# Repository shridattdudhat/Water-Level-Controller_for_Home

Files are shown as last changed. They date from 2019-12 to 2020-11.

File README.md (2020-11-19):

# DIY_WaterLevel_For_Home
Simple Water Level Controller Using Arduino
Water Level
Automatic detects Water level of Tank and turn on and off motor according to it
https://shridatt.github.io
modified 27 Oct 2019 Diwali
by Shridatt Dudhat
           _            _
           |         G  |  => H
           |            |
           |            |
           |         R  |  => L
           |            |
           |            |
           \_________B__/  => GND
This code is in the public domain.
http://shridattdudhat.github.io









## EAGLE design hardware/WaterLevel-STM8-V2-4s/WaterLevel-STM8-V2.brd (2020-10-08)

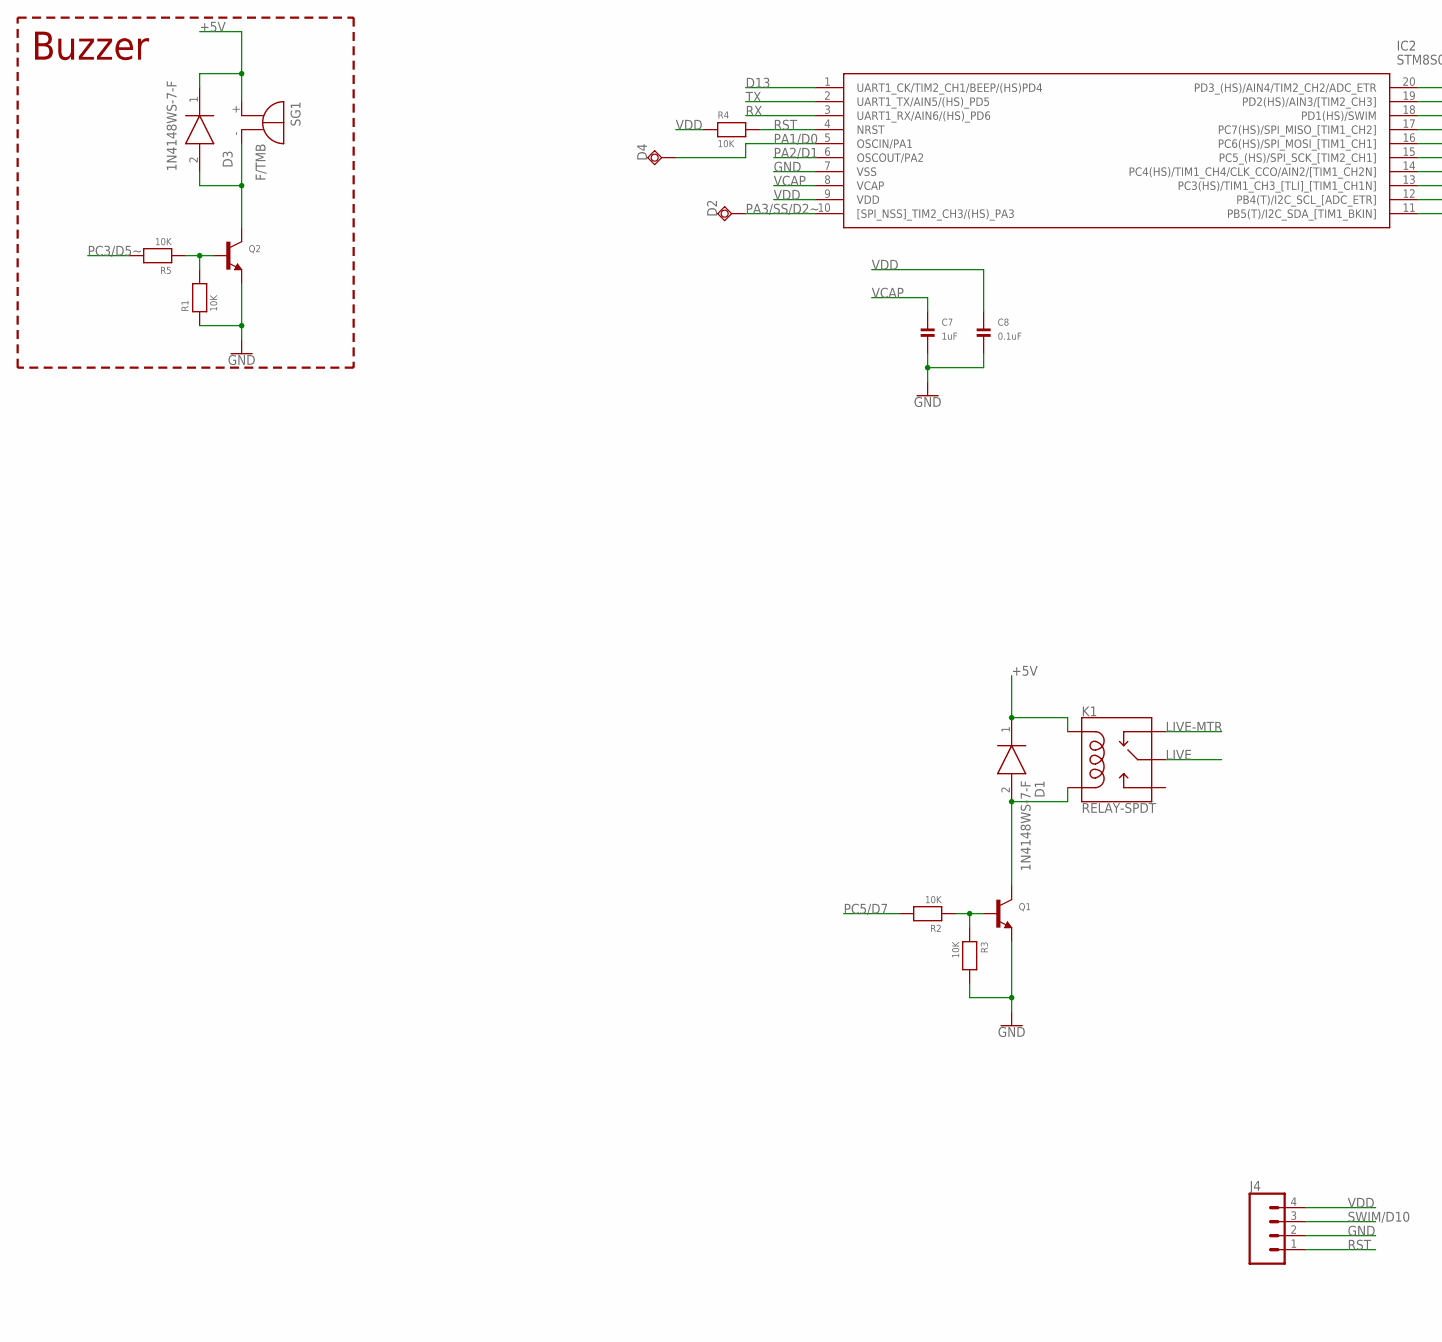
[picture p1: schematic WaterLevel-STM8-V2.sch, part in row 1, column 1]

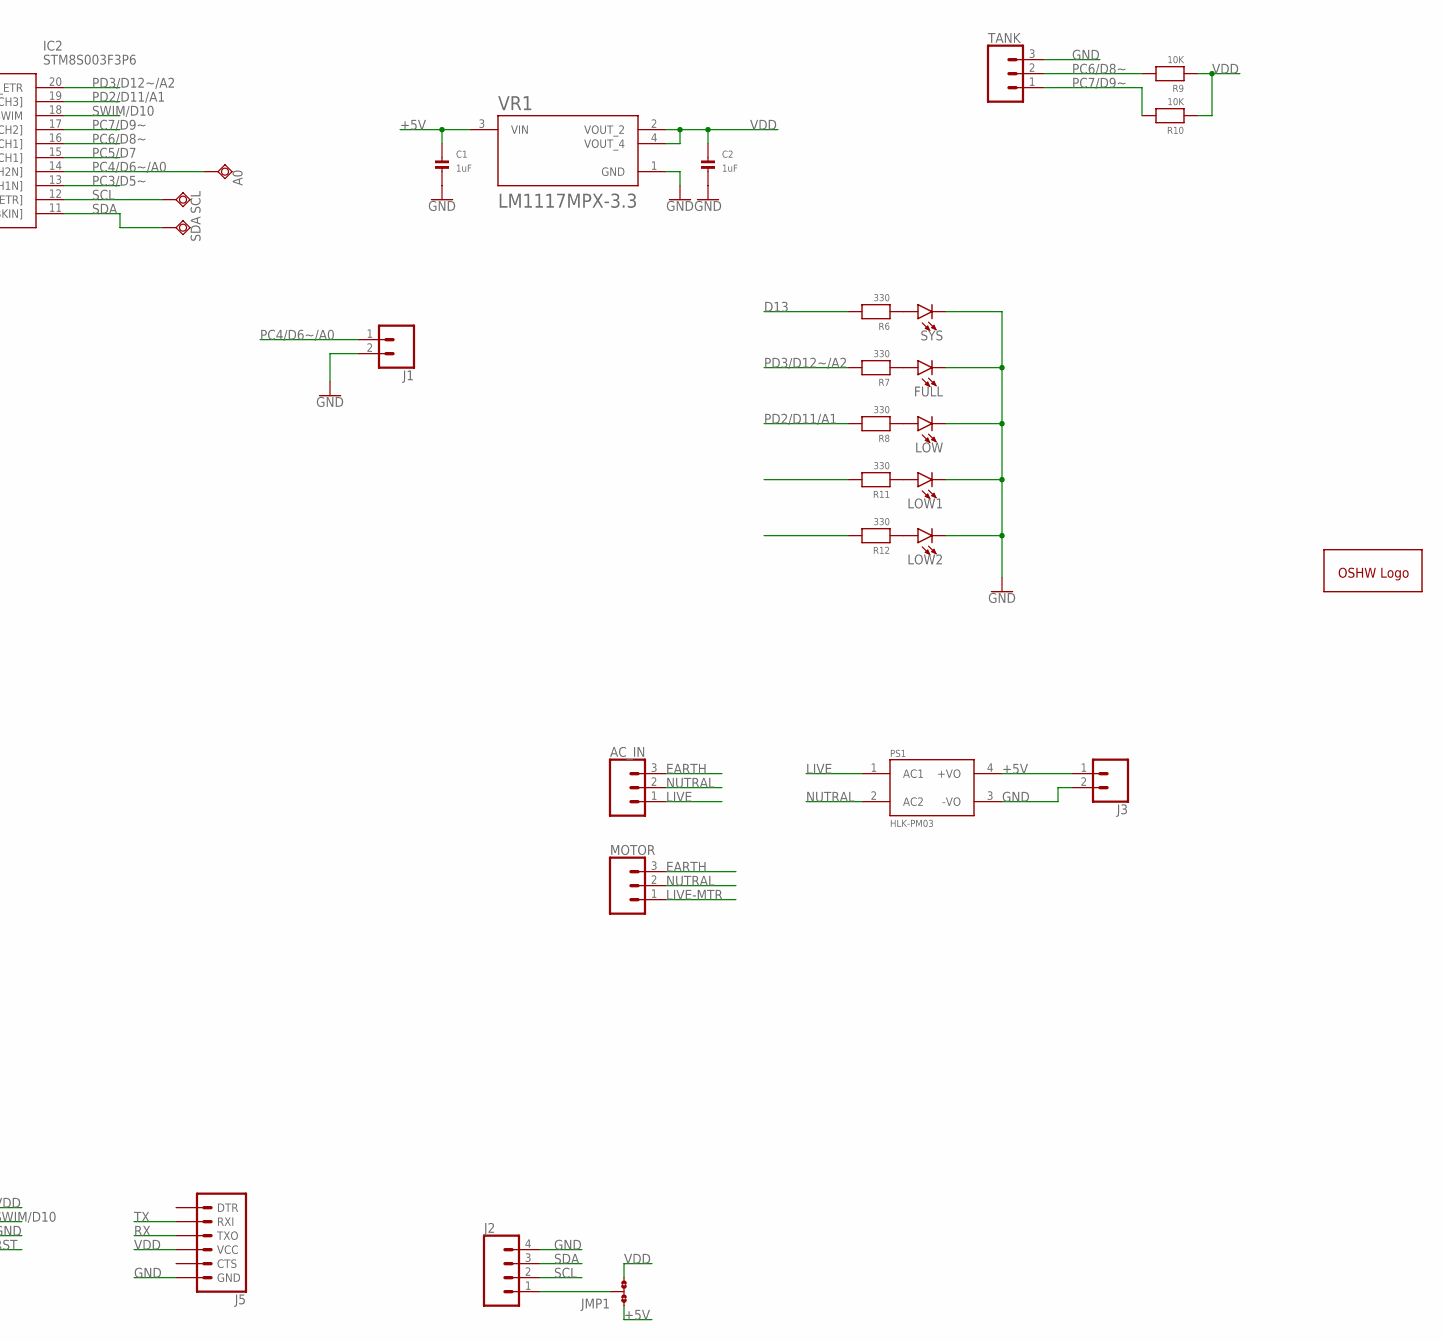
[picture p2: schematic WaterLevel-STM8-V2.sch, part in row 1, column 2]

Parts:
A0: TPSQTP20R; TP20R
AC_IN: SCREW-CONN_03-SCREW-5MM; SCREWTERMINAL-5MM-3
C1, C2, C7: 1uF; C0805
C8: 0.1uF; C0805
D1, D3: 1N4148WS-7-F; SOD2513X120N
D2, D4: TPSQTP20R; TP20R
FULL: LED-5MM-REC5MM; LED_5MM
GOLD_ORB_SM1: OSHWLOGOLOGO16MM; OSHW_16MM
IC2: STM8S003F3P6; SOP65P640X120-20N
J1, J3: 2PIN-2.54MM-POLARPOLAR; MOLEX-1X2
J2, J4: CONN_04PTH; 1X04
J5: 6_PIN_SERIAL_TARGETSILK; 6_PIN_SERIAL_TARGET_SIDE_W_SILK
JMP1: JMP-3-NO
K1: RELAY-SPDT; RELAY_G5LE
LOW, LOW1, LOW2: LED-5MM-REC5MM; LED_5MM
MOTOR: SCREW-CONN_03-SCREW-5MM; SCREWTERMINAL-5MM-3
PS1: HLK-PM03; CONV_HLK-PM03
Q1, Q2: TRANSISTOR_NPNWIDE; SOT23-WIDE
R1, R2, R3, R4, R5, R9, R10: 10K; R0805
R6, R7, R8, R11, R12: 330; R0805
SCL: TPSQTP20R; TP20R
SDA: TPSQTP20R; TP20R
SG1: F/TMB
SYS: LED-5MM-REC5MM; LED_5MM
TANK: SCREW-CONN_03-SCREW-5MM; SCREWTERMINAL-5MM-3
VR1: LM1117MPX-3.3; VREG_LM1117MPX-3.3

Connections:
+5V: C1.1, D1.1 (K), D3.1 (K), J3.1, JMP1.1, K1.2 (COIL1), PS1.4 (+VO), SG1.+, VR1.3 (VIN)
D13: IC2.1 (UART1_CK/TIM2_CH1/BEEP/(HS)PD4), R6.2
EARTH: AC_IN.3, MOTOR.3
GND: C1.2, C2.2, C7.2, C8.2, FULL.K (C), IC2.7 (VSS), J1.2, J2.4, J3.2, J4.2, J5.P$6 (GND), LOW.K (C), LOW1.K (C), LOW2.K (C), PS1.3 (-VO), Q1.2 (E), Q2.2 (E), R1.1, R3.2, SYS.K (C), TANK.3, VR1.1 (GND)
LIVE: AC_IN.1, K1.1 (MAIN), PS1.1 (AC1)
LIVE-MTR: K1.4 (NC), MOTOR.1
unnamed: R6.1, SYS.A
unnamed: D1.2 (A), K1.5 (COIL2), Q1.3 (C)
unnamed: Q1.1 (B), R2.1, R3.1
unnamed: D3.2 (A), Q2.3 (C), SG1.-
unnamed: Q2.1 (B), R1.2, R5.1
unnamed: FULL.A, R7.1
unnamed: LOW.A, R8.1
unnamed: J2.1, JMP1.2
unnamed: LOW1.A, R11.1
unnamed: LOW2.A, R12.1
NUTRAL: AC_IN.2, MOTOR.2, PS1.2 (AC2)
PA1/D0: D4.TP, IC2.5 (OSCIN/PA1)
PA2/D1: IC2.6 (OSCOUT/PA2)
PA3/SS/D2~: D2.TP, IC2.10 ([SPI_NSS]_TIM2_CH3/(HS)_PA3)
PC3/D5~: IC2.13 (PC3(HS)/TIM1_CH3_[TLI]_[TIM1_CH1N]), R5.2
PC4/D6~/A0: A0.TP, IC2.14 (PC4(HS)/TIM1_CH4/CLK_CCO/AIN2/[TIM1_CH2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), J1.1
PC5/D7: IC2.15 (PC5_(HS)/SPI_SCK_[TIM2_CH1]), R2.2
PC6/D8~: IC2.16 (PC6(HS)/SPI_MOSI_[TIM1_CH1]), R9.2, TANK.2
PC7/D9~: IC2.17 (PC7(HS)/SPI_MISO_[TIM1_CH2]), R10.2, TANK.1
PD2/D11/A1: IC2.19 (PD2(HS)/AIN3/[TIM2_CH3]), R8.2
PD3/D12~/A2: IC2.20 (PD3_(HS)/AIN4/TIM2_CH2/ADC_ETR), R7.2
RST: IC2.4 (NRST), J4.1, R4.2
RX: IC2.3 (UART1_RX/AIN6/(HS)_PD6), J5.P$2 (TXO)
SCL: IC2.12 (PB4(T)/I2C_SCL_[ADC_ETR]), J2.2, SCL.TP
SDA: IC2.11 (PB5(T)/I2C_SDA_[TIM1_BKIN]), J2.3, SDA.TP
SWIM/D10: IC2.18 (PD1(HS)/SWIM), J4.3
TX: IC2.2 (UART1_TX/AIN5/(HS)_PD5), J5.P$3 (RXI)
VCAP: C7.1, IC2.8 (VCAP)
VDD: C2.1, C8.1, IC2.9 (VDD), J4.4, J5.P$4 (VCC), JMP1.3, R4.1, R9.1, R10.1, VR1.2 (VOUT_2), VR1.4 (VOUT_4)

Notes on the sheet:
Buzzer

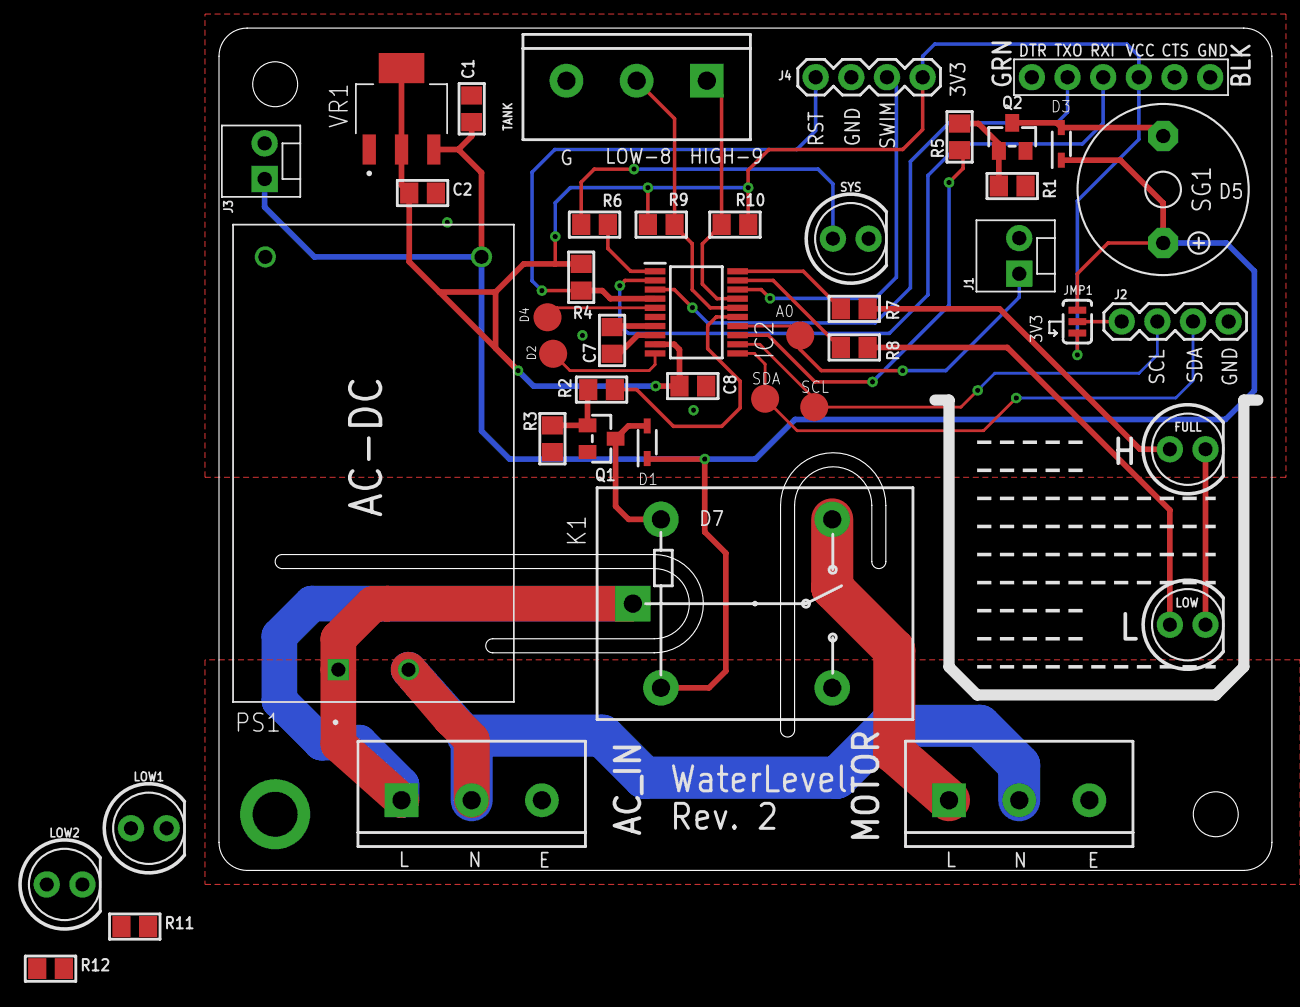
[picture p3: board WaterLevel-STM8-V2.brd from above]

Board: 2 copper layers, 75.0 x 60.0 mm, 45 parts (1 on the bottom side), 34 nets.

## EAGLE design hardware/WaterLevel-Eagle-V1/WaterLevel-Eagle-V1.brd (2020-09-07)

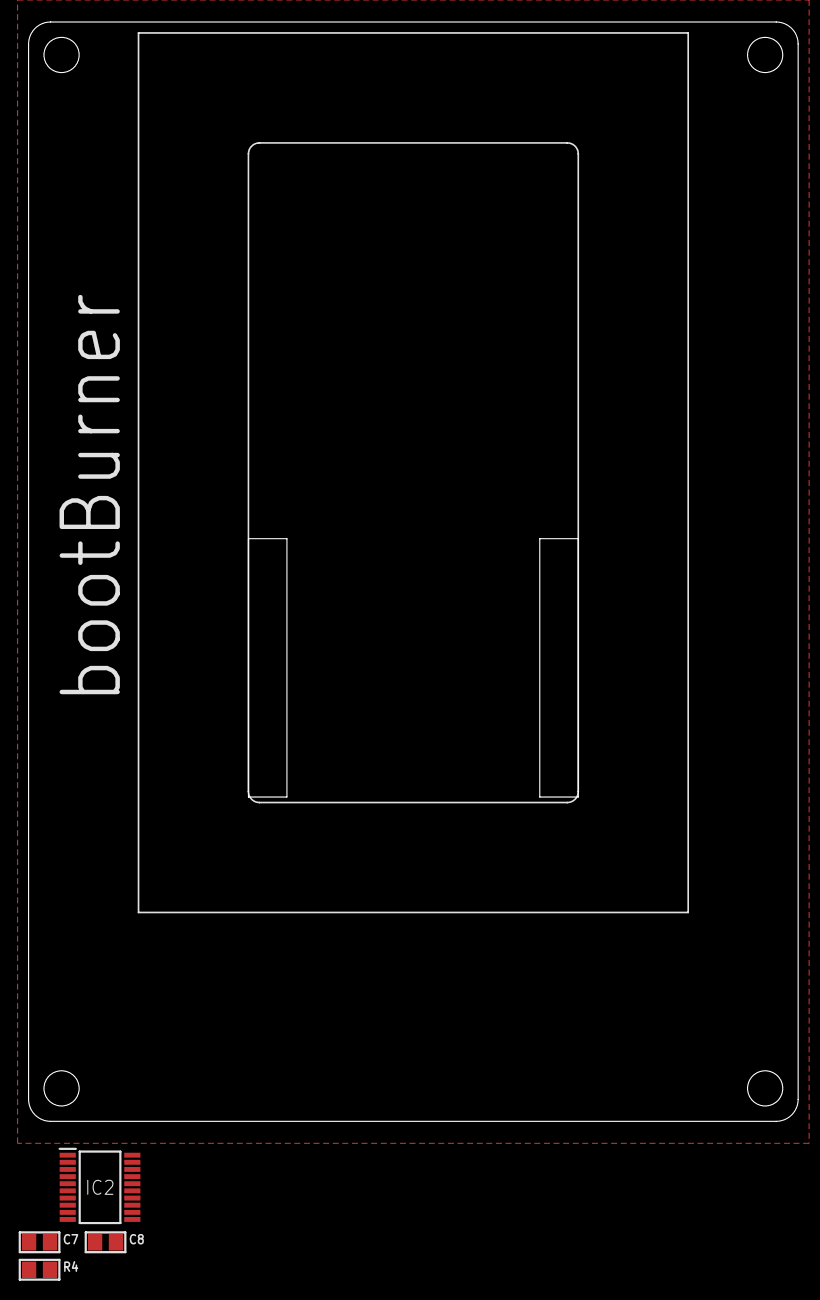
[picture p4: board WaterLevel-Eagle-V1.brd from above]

Board: 2 copper layers, 70.0 x 100.0 mm, 4 parts (0 on the bottom side), 4 nets, no tracks yet.

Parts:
C7: 1uF; C0805
C8: 0.1uF; C0805
IC2: STM8S003F3P6; SOP65P640X120-20N
R4: 10K; R0805

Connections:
GND: C7.2, C8.2, IC2.7
RST: IC2.4, R4.2
VCAP: C7.1, IC2.8
VDD: C8.1, IC2.9, R4.1

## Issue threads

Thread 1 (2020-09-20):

Create PCB for the WaterLevel

shridattdudhat, 2020-09-20:

shridattdudhat, 2020-09-20:
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

Component Placement

shridattdudhat, 2020-09-26:
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

shridattdudhat, 2020-09-29:
Need to add manual switch connector,
If water level feedback not works we can use the manual switch to force the motor on

shridattdudhat, 2020-10-05:
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

shridattdudhat, 2020-11-19:
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

Closed 2020-11-19.

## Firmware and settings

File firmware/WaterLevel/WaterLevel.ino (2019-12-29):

/*
  Water Level

  Automatic detects Water level of Tank and turn on and off motor according to it

  https://shridatt.github.io

  modified 27 Oct 2019 Diwali
  by Shridatt Dudhat

           _            _
           |         G  |  => H
           |            |
           |            |
           |         R  |  => L
           |            |
           |            |
           \_________B__/  => GND

  This code is in the public domain.

  http://shridattdudhat.github.io

*/

#define motor      12
#define GREEN       2
#define RED         3
#define buzzer     11
#define SW          7
#define statusLED  13
#define LEDG       A0
#define LEDR       A1
#define R           5
#define G           6
#define B           9

bool ledState = LOW;
bool motorFlag = HIGH;

unsigned long previousMillis = 0;
const long interval = 500;

void setup() {

  Serial.begin(9600);
  /*Setting up the pinModes*/
  pinMode(statusLED, OUTPUT);
  pinMode(LEDG, OUTPUT);
  pinMode(LEDR, OUTPUT);
  pinMode(R, OUTPUT);
  pinMode(G, OUTPUT);
  pinMode(B, OUTPUT);
  digitalWrite(R, HIGH);
  digitalWrite(G, HIGH);
  digitalWrite(B, HIGH);

  pinMode(GREEN, INPUT_PULLUP);
  pinMode(RED, INPUT_PULLUP);

  pinMode(SW, INPUT_PULLUP);

  pinMode(motor, OUTPUT);

  motorState(LOW); //Initially motor is off
  delay(5000);
  motorState(HIGH); // turn on motor after 5 seconds
}

void loop() {

  unsigned long currentMillis = millis();

  if (currentMillis - previousMillis >= interval)
  {
    previousMillis = currentMillis;
    if (ledState == LOW)
    {
      ledState = HIGH;
    }
    else
    {
      ledState = LOW;
    }
    digitalWrite(LEDG, ledState);
  }

  int SW_state = digitalRead(SW);

  if (SW_state == 0)
  {
    manual();
  }
  else
  {
    automatic();
  }
}


void automatic()
{
  Serial.println("Automatic Mode !");
  int H = digitalRead(GREEN);
  int L = digitalRead(RED);
  if (L == 1 && H == 1)                     //Tank Empty
  {
    if (motorFlag == HIGH)
    {
      motorState(HIGH);                       //Motor is on
    }
    color(1, 0, 0);                         //RED
    Serial.println("Motor ON!");
  }

  if (L == 0 && H == 1)                     //Tank Half
  {
    color(0, 1, 0);                         //GREEN
  }

  if (L == 0 && H == 0)                    //Tank Full
  {
    motorFlag = LOW;
    motorState(LOW);                        //Motor is off
    alert();
    color(0, 0, 1);                         //BLUE
    Serial.println("Motor OFF!");
  }
}

//-------------Manual Function----------------//
/* Motor will run directly if the switch is pressed*/
void manual()
{
  Serial.println("Manual Mode !");
  motorState(HIGH);                       // Motor is on
  color(1, 0, 0);
  delay(100);
  color(0, 1, 0);
  delay(100);
  color(0, 0, 1);
  delay(100);
}
//-------------RGB Function----------------//
void color(int red_value, int green_value, int blue_value)
{
  digitalWrite(R, !red_value);
  digitalWrite(G, !green_value);
  digitalWrite(B, !blue_value);
}
//-------------Buzzer Function----------------//
void alert()
{
  digitalWrite(buzzer, HIGH);
  delay(100);
  digitalWrite(buzzer, LOW);
  delay(100);
}
//-------------Motor Function----------------//
void motorState(bool x)
{
  digitalWrite(motor, !x);
}

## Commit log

2019-12-03 motorFlag added to avoid false trigger of motor ON
    [WaterLevel.ino]
2019-12-29 Motor State error resolved
    [WaterLevel.ino]
2020-09-07 hardware for waterlevel controller
    [WaterLevel-Eagle-V1.brd, WaterLevel-Eagle-V1.sch]
2020-09-20 #1 component placement in the PCB
    [WaterLevel-Eagle-V1.sch]
2020-09-20 #1 Eagle Project renamed
    [WaterLevel-STM8-V1.brd, WaterLevel-STM8-V1.sch]
2020-09-26 #1 New PCB update
    [WaterLevel-STM8-V1.brd, WaterLevel-STM8-V1.sch]
2020-10-01 Added I2C connector and Manual Switch to the board
    [WaterLevel-STM8-V1.brd, WaterLevel-STM8-V1.sch]
2020-10-04 #1 New Gerber Generation with Manual Switch and I2C connector for other sensors
2020-10-08 V2 with 4Sensor prob
    [WaterLevel-STM8-V2.brd, WaterLevel-STM8-V2.sch]

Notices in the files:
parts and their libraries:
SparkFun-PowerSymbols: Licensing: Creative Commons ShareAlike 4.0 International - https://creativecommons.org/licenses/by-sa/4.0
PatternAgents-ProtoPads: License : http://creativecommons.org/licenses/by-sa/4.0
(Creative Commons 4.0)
